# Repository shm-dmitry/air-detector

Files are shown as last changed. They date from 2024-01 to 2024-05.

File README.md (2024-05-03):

Project info
=======

Project released.

This project contains 2 boards with different sensor sets.

Board#1:
- CO2
- TVOC
- NOx
- Temperature
- Humidity
- PMx (dust)
- H2S (hydrogen sulfide)
- CO (carbon monoxide)
- O2 (oxygen)

Board#2
- TVOC
- NOx
- Temperature
- Humidity
- H2S (hydrogen sulfide)
- Light (in percents, not in Lumens)

It controls:
- Exhaust fan 
- Cooling fan with speed control (fan_pwm driver) 

Additional features:
- Integrates with any smart-house system via MQTT protocol (over WIFI)
- Contains touchpad supports multi-click (single click, double click, tripple click etc)
- Contains RGB led to indicate some internal state you want
- OTA updates - just publish new firmware on your local HTTP server and send URL to it into MQTT topic

3D models
=======
- Board#1 - 3d/box-slepingroom*.stl
- Board#2 - 3d/box-bathroom*.stl

Home assistant files
=======
- Board#1 - hass/board1
- Board#2 - hass/board2

Project status
=======

- Board#1 - Done
- Board#2 - Done

Photos
=======
Board#1:






Board#2:
изображение
изображение
изображение
изображение

MQTT Broker data:

Board#1: topic `/air/1`

Board#2: topic `/air/0`

изображение

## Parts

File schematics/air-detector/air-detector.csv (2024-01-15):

Source: | /opt/work-iot/air-detector/schematics/air-detector/air-detector.kicad_sch
Date: | Вт 09 янв 2024 12:32:36
Tool: | Eeschema 7.0.10-7.0.10~ubuntu22.04.1
Generator: | /usr/share/kicad/plugins/bom_csv_grouped_by_value_with_fp.py
Component Count: | 132
Ref | Qnty | Value | Cmp name | Footprint | Description | Vendor | DNP
C1, C2, C3, C6, C27, C28, C29 | 7 | 10 uF | C | Capacitor_SMD:C_0603_1608Metric | Unpolarized capacitor
C4, C11, C30, C33 | 4 | 1000 uF | C_Polarized | Capacitor_THT:CP_Radial_D8.0mm_P3.50mm | Polarized capacitor
C5, C9, C17, C31, C32, C36 | 6 | 22 uF | C | Capacitor_SMD:C_1210_3225Metric | Unpolarized capacitor
C7, C8, C10, C12, C14, C15, C19, C20, C21, C23, C24, C25, C34, C39, C40, C41 | 16 | 1 uF | C | Capacitor_SMD:C_0603_1608Metric | Unpolarized capacitor
C13, C26 | 2 | 100 nF | C | Capacitor_SMD:C_0603_1608Metric | Unpolarized capacitor
C16, C22, C35 | 3 | 100 uF | C | Capacitor_SMD:C_0603_1608Metric | Unpolarized capacitor
C18, C37, C38 | 3 | 0.1 uF | C | Capacitor_SMD:C_0603_1608Metric | Unpolarized capacitor
D4 | 1 | SK6812 | SK6812 | LED_SMD:LED_SK6812_PLCC4_5.0x5.0mm_P3.2mm | RGB LED with integrated controller
D8, D9 | 2 | PRTR5V0U2X | SP0503BAHT | Package_TO_SOT_SMD:SOT-143 | TVS Diode Array, 5.5V Standoff, 3 Channels, SOT-143 package
H1, H2, H3, H4, H5, H6, H7, H8, H9 | 9 | MountingHole | MountingHole | MountingHole:MountingHole_2.2mm_M2 | Mounting Hole without connection
J1, J9 | 2 | USB_C_Receptacle_USB2.0 | USB_C_Receptacle_USB2.0 | Library:USB_C_P16_MIDMOUNT_1.6 | USB 2.0-only Type-C Receptacle connector
J2 | 1 | Touch sensor | Conn_01x02_Socket | Connector_JST:JST_XH_B2B-XH-A_1x02_P2.50mm_Vertical | Generic connector, single row, 01x02, script generated
J3, J10 | 2 | 5V input | Conn_01x02_Socket | Connector_JST:JST_XH_B2B-XH-A_1x02_P2.50mm_Vertical | Generic connector, single row, 01x02, script generated
J4, J8 | 2 | BME280 | Conn_01x04_Socket | Connector_JST:JST_XH_B4B-XH-A_1x04_P2.50mm_Vertical | Generic connector, single row, 01x04, script generated
J5 | 1 | PMS7003 | Conn_02x05_Odd_Even | Connector_JST:JST_XH_B10B-XH-A_1x10_P2.50mm_Vertical | Generic connector, double row, 02x05, odd/even pin numbering scheme (row 1 odd numbers, row 2 even numbers), script generated (kicad-library-utils/schlib/autogen/connector/)
J6 | 1 | Ext FAN | Conn_01x02_Socket | Connector_JST:JST_XH_B2B-XH-A_1x02_P2.50mm_Vertical | Generic connector, single row, 01x02, script generated
J7 | 1 | FAN | Conn_01x02_Socket | Connector_JST:JST_XH_B2B-XH-A_1x02_P2.50mm_Vertical | Generic connector, single row, 01x02, script generated
J11 | 1 | MHZ19B | Conn_01x04_Socket | Connector_JST:JST_XH_B4B-XH-A_1x04_P2.50mm_Vertical | Generic connector, single row, 01x04, script generated
JP1, JP3 | 2 | FLUSH | SolderJumper_2_Open | Jumper:SolderJumper-2_P1.3mm_Open_TrianglePad1.0x1.5mm | Solder Jumper, 2-pole, open
JP2, JP4 | 2 | RESET | SolderJumper_2_Open | Jumper:SolderJumper-2_P1.3mm_Open_TrianglePad1.0x1.5mm | Solder Jumper, 2-pole, open
Q1, Q2, Q6, Q7 | 4 | BC847 | BC847 | Package_TO_SOT_SMD:SOT-23 | 0.1A Ic, 45V Vce, NPN Transistor, SOT-23
Q3, Q4, Q5 | 3 | IRLML0030 | IRLML0030 | Package_TO_SOT_SMD:SOT-23 | 5.3A Id, 30V Vds, 27mOhm Rds, N-Channel HEXFET Power MOSFET, SOT-23
R1, R24 | 2 | 22K | R | Resistor_SMD:R_0805_2012Metric | Resistor
R2, R25 | 2 | 44K | R | Resistor_SMD:R_0805_2012Metric | Resistor
R3, R14, R15, R26, R29, R31 | 6 | 1K | R | Resistor_SMD:R_0805_2012Metric | Resistor
R4, R5, R7, R9, R17, R18, R22, R23, R27, R28, R30, R32, R33, R34, R35, R36, R37 | 17 | 10K | R | Resistor_SMD:R_0805_2012Metric | Resistor
R6 | 1 | 100 | R | Resistor_SMD:R_0805_2012Metric | Resistor
R8 | 1 | 10K | R_Photo | Resistor_THT:R_Axial_DIN0207_L6.3mm_D2.5mm_P2.54mm_Vertical | Photoresistor
R10, R11, R12, R13 | 4 | 3K3 | R | Resistor_SMD:R_0805_2012Metric | Resistor
R16, R20 | 2 | 4R7 | R | Resistor_SMD:R_0805_2012Metric | Resistor
R19 | 1 | 500 | R | Resistor_SMD:R_0805_2012Metric | Resistor
R21 | 1 | 30K | R | Resistor_SMD:R_0805_2012Metric | Resistor
RV1 | 1 | 5K | R_Potentiometer | Potentiometer_THT:Potentiometer_Runtron_RM-065_Vertical | Potentiometer
RV2, RV3 | 2 | 200K | R_Potentiometer | Potentiometer_THT:Potentiometer_Runtron_RM-065_Vertical | Potentiometer
SW1, SW2, SW3, SW4 | 4 | KLS7-TS3601-5.0-180 | SW_Push | Library:SW_PUSH_P6.5_W3.5 | Push button switch, generic, two pins
U1, U13 | 2 | CP2102N-Axx-xQFN28 | CP2102N-Axx-xQFN28 | Package_DFN_QFN:QFN-28-1EP_5x5mm_P0.5mm_EP3.35x3.35mm | USB to UART master bridge, QFN-28
U2 | 1 | O2A2 | O2A2 | Library:O2A2
U3 | 1 | LM358ADR | LM2904 | Package_SO:SOP-8_5.28x5.23mm_P1.27mm | Dual Operational Amplifiers, DIP-8/SOIC-8/TSSOP-8/VSSOP-8
U4, U14 | 2 | AMS1117-3.3 | AMS1117-3.3 | Package_TO_SOT_SMD:SOT-223-3_TabPin2 | 1A Low Dropout regulator, positive, 3.3V fixed output, SOT-223
U5 | 1 | MQ-7 | MQ-6 | Sensor:MQ-6 | Semiconductor Sensor for Flammable Gas
U6, U12 | 2 | MQ-136 | MQ-6 | Sensor:MQ-6 | Semiconductor Sensor for Flammable Gas
U8, U15 | 2 | ESP32-WROOM-32 | ESP32-WROOM-32 | RF_Module:ESP32-WROOM-32 | RF Module, ESP32-D0WDQ6 SoC, Wi-Fi 802.11b/g/n, Bluetooth, BLE, 32-bit, 2.7-3.6V, onboard antenna, SMD
U10, U11 | 2 | SGP41 | SGP41 | footprints:XDCR_SGP41-D-R4

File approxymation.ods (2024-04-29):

X | 10 | Y | 1,45 | 1,45000054672845
X | 25 | Y | 1,13 | 1,13000041804603
X | 40 | Y | 1 | 1,00000045075979
X | 55 | Y | 0,92 | 0,920000474232243
X | 70 | Y | 0,87 | 0,870000487142095
OFFSET | 20
A | 0,746382 | 1,689218
B | 0,031302 | 0,266425
C | 0,786563
Test: | X | 44,2 | Y | 0,973684573079186

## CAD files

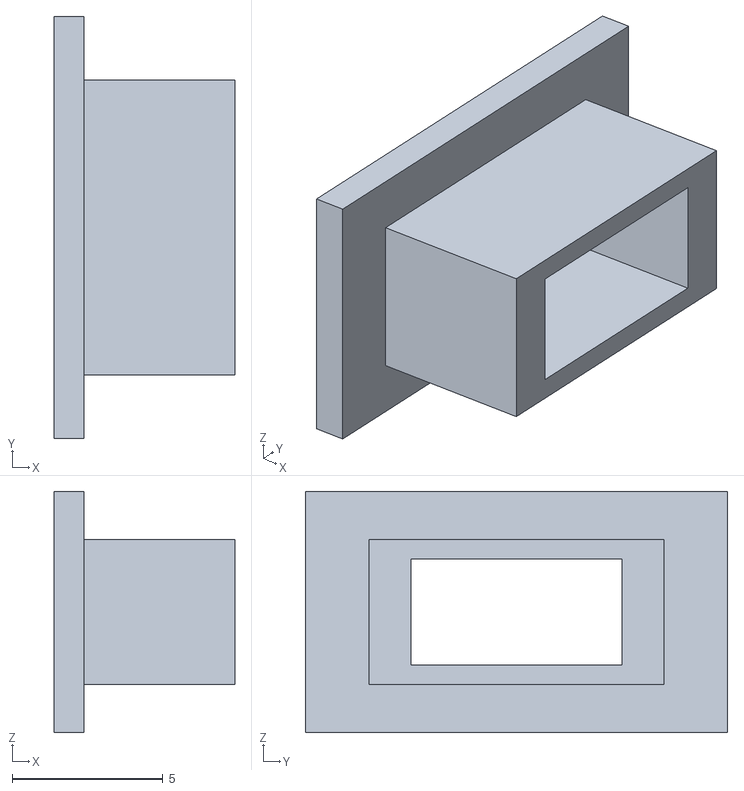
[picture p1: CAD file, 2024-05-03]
3d/box-slepingroom-wire-holder.stl
6.00 x 14.0 x 8.00

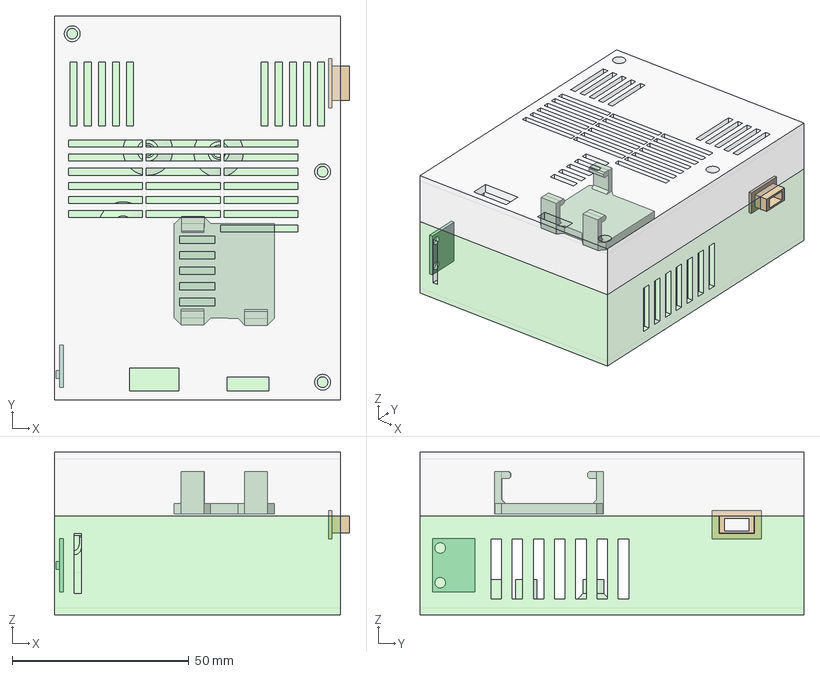
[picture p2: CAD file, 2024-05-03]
3d/box-slepingroom.FCStd
83.4 x 108.5 x 46.0 mm
bme280
cup
mhz19b-lock
wire-holder

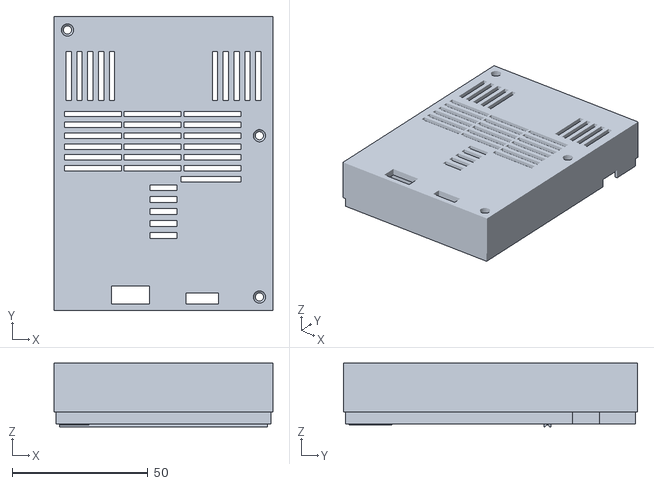
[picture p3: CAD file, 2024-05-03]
3d/box-slepingroom-cup.stl
80.8 x 108.5 x 23.5

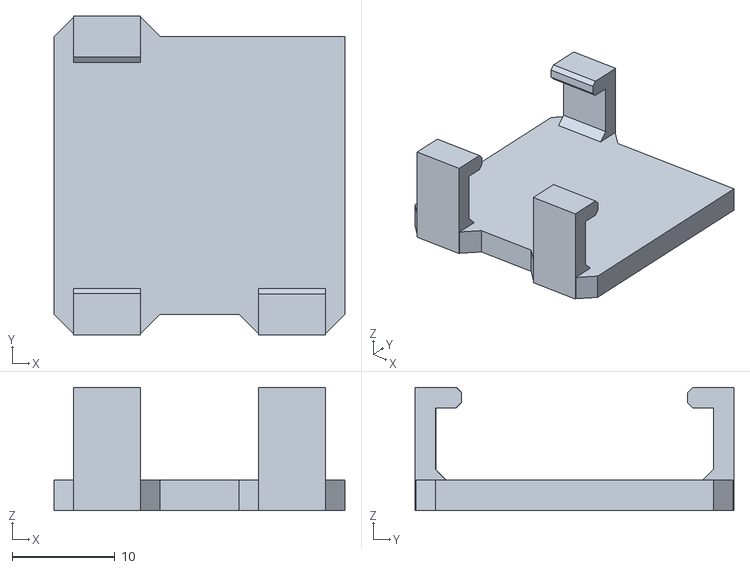
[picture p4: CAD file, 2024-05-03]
3d/box-slepingroom-mhz19b-lock.stl
28.3 x 31.0 x 12.0

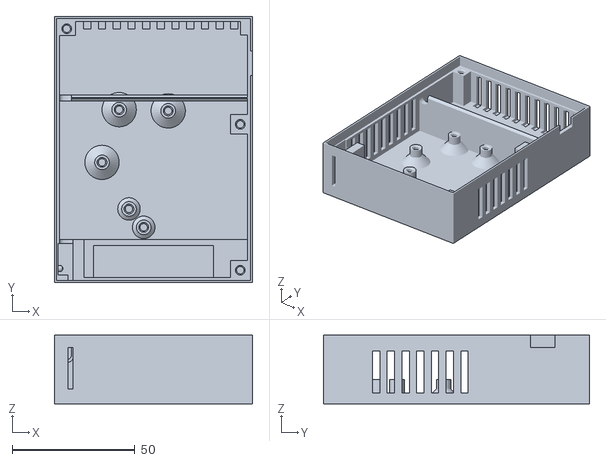
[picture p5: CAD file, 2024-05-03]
3d/box-slepingroom-box.stl
80.8 x 108.5 x 28.0

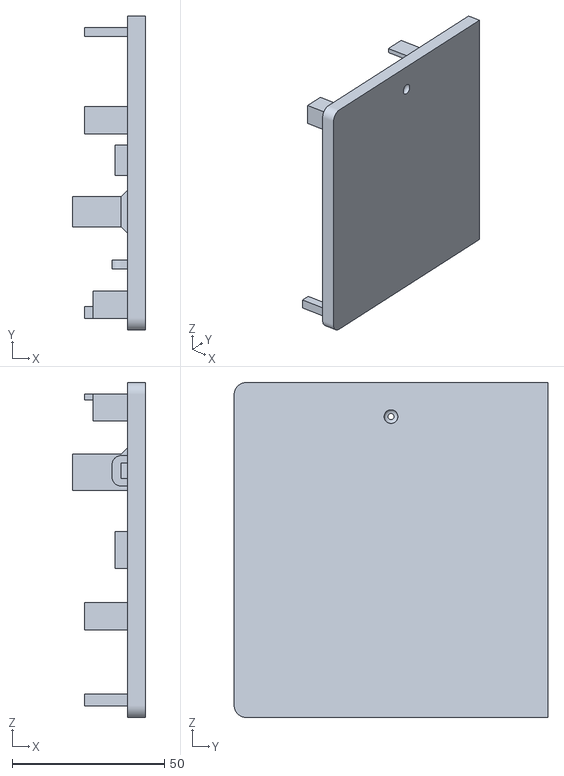
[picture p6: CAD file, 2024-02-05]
3d/box-bathroom-cup.stl
24.0 x 103.0 x 110.0

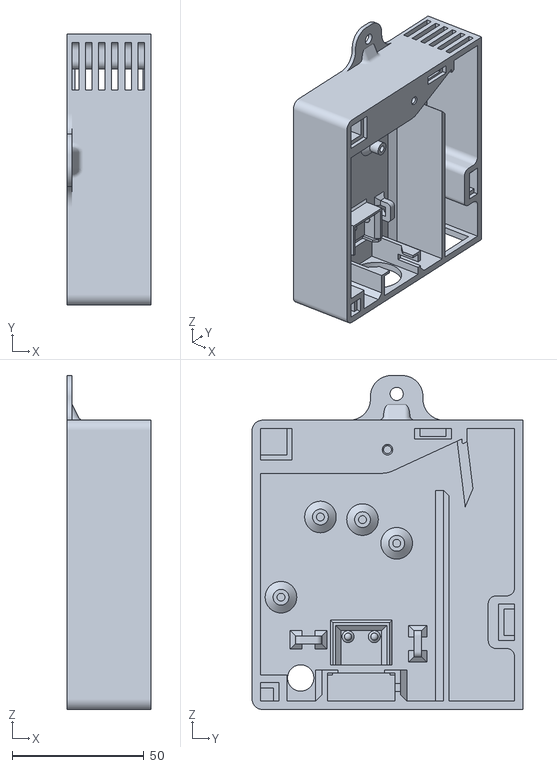
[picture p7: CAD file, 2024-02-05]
3d/box-bathroom-box.stl
32.0 x 103.0 x 127.0

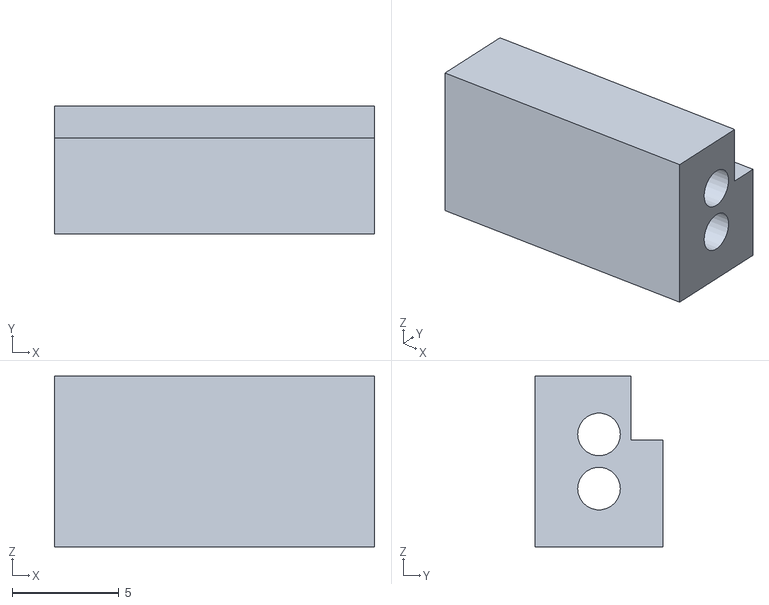
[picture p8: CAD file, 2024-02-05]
3d/box-bathroom-light-sensor-holder.stl
15.0 x 6.00 x 8.00

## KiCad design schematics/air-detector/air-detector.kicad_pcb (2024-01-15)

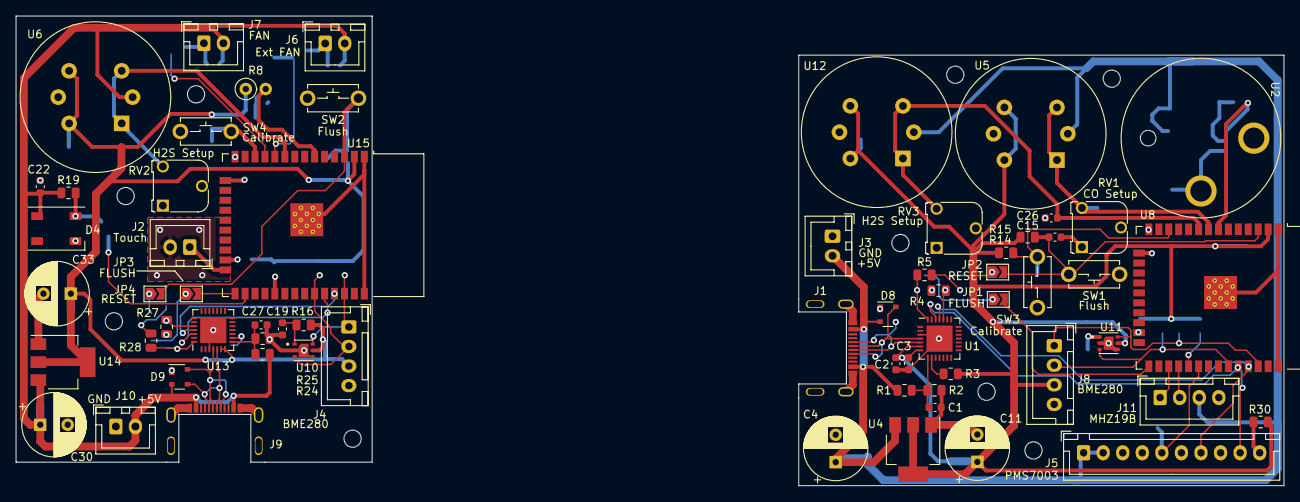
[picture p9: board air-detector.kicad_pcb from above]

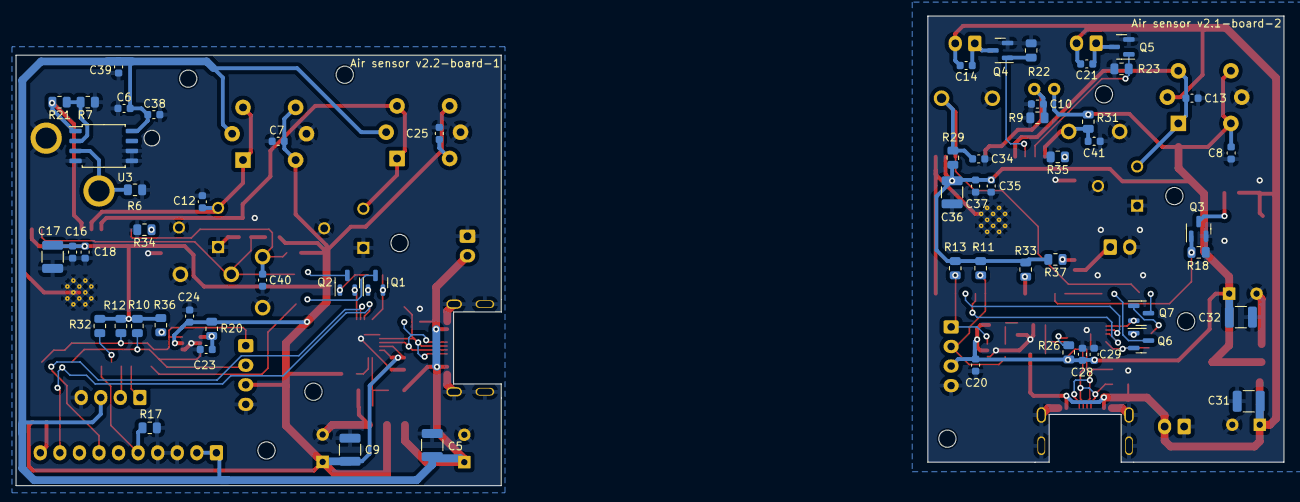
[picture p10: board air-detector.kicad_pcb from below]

Board: 2 copper layers, 162.0 x 60.0 mm, 132 parts (59 on the bottom side), 66 nets.

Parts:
C1, C2, C3, C6, C27, C28, C29: 10 uF; C_0603_1608Metric
C4, C11, C30, C33: 1000 uF; CP_Radial_D8.0mm_P3.50mm
C5, C9, C17, C31, C32, C36: 22 uF; C_1210_3225Metric
C7, C8, C10, C12, C14, C15, C19, C20, C21, C23, C24, C25, C34, C39, C40, C41: 1 uF; C_0603_1608Metric
C13, C26: 100 nF; C_0603_1608Metric
C16, C22, C35: 100 uF; C_0603_1608Metric
C18, C37, C38: 0.1 uF; C_0603_1608Metric
D4: SK6812; LED_SK6812_PLCC4_5.0x5.0mm_P3.2mm
D8, D9: PRTR5V0U2X; SOT-143
H1, H2, H3, H4, H5, H6, H7, H8, H9: MountingHole; MountingHole_2.2mm_M2
J1, J9: USB_C_Receptacle_USB2.0; USB_C_P16_MIDMOUNT_1.6
J2: Touch sensor; JST_XH_B2B-XH-A_1x02_P2.50mm_Vertical
J3, J10: 5V input; JST_XH_B2B-XH-A_1x02_P2.50mm_Vertical
J4, J8: BME280; JST_XH_B4B-XH-A_1x04_P2.50mm_Vertical
J5: PMS7003; JST_XH_B10B-XH-A_1x10_P2.50mm_Vertical
J6: Ext FAN; JST_XH_B2B-XH-A_1x02_P2.50mm_Vertical
J7: FAN; JST_XH_B2B-XH-A_1x02_P2.50mm_Vertical
J11: MHZ19B; JST_XH_B4B-XH-A_1x04_P2.50mm_Vertical
JP1, JP3: FLUSH; SolderJumper-2_P1.3mm_Open_TrianglePad1.0x1.5mm
JP2, JP4: RESET; SolderJumper-2_P1.3mm_Open_TrianglePad1.0x1.5mm
Q1, Q2, Q6, Q7: BC847; SOT-23
Q3, Q4, Q5: IRLML0030; SOT-23
R1, R24: 22K; R_0805_2012Metric
R2, R25: 44K; R_0805_2012Metric
R3, R14, R15, R26, R29, R31: 1K; R_0805_2012Metric
R4, R5, R7, R17, R18, R22, R23, R27, R28, R30, R32, R33, R34, R35, R36, R37: 10K; R_0805_2012Metric
R6: 100; R_0805_2012Metric
R8: 100K; R_Axial_DIN0207_L6.3mm_D2.5mm_P2.54mm_Vertical
R9: 100K; R_0805_2012Metric
R10, R11, R12, R13: 3K3; R_0805_2012Metric
R16, R20: 4R7; R_0805_2012Metric
R19: 500; R_0805_2012Metric
R21: 30K; R_0805_2012Metric
RV1: 10K; Potentiometer_Runtron_RM-065_Vertical
RV2, RV3: 20K; Potentiometer_Runtron_RM-065_Vertical
SW1, SW2, SW3, SW4: KLS7-TS3601-5.0-180; SW_PUSH_P6.5_W3.5
U1, U13: CP2102N-Axx-xQFN28; QFN-28-1EP_5x5mm_P0.5mm_EP3.35x3.35mm
U2: O2A2
U3: LM358ADR; SOP-8_5.28x5.23mm_P1.27mm
U4, U14: AMS1117-3.3; SOT-223-3_TabPin2
U5: MQ-7; MQ-6
U6, U12: MQ-136; MQ-6
U8, U15: ESP32-WROOM-32
U10, U11: SGP41; XDCR_SGP41-D-R4

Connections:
/board1/+3V3: C2.1, C3.1, C7.2, C9.2, C11.1, C16.2, C17.2, C18.1, C24.2, C25.2, J8.3, R3.2, R10.1, R12.1, R14.1, R15.1, R20.1, R30.2, R32.2, R36.2, U1.6 (VDD), U1.7 (VREGIN), U4.2 (VO), U5.4 (A2), U5.6 (A1), U8.2 (VDD), U11.5 (VCC_H), U12.4 (A2), U12.6 (A1)
/board1/+5V: C4.1, C5.2, C6.2, C38.2, C39.2, D8.2 (K), J1.A4 (VBUS), J1.A9 (VBUS), J1.B4 (VBUS), J1.B9 (VBUS), J3.2, J5.1, J5.2, J11.3, R1.1, U3.8 (V+), U4.3 (VI), U5.2 (VH+), U12.2 (VH+)
/board1/CO: C12.2, RV1.3, U5.1 (B1), U5.3 (B2), U8.8 (IO32)
/board1/H2S: C26.2, RV3.3, U8.9 (IO33), U12.1 (B1), U12.3 (B2)
/board1/O2: R21.2, U3.1, U8.7 (IO35)
/board1/PMS7003_ENABLE: J5.5, R17.2, U8.30 (IO18)
/board1/RXD_2_3V3: J11.2, U8.28 (IO17)
/board1/RXD_3V3: J5.7, U1.25 (RXD), U8.35 (TXD0/IO1)
/board1/SCL_3V3: J8.1, R12.2, U8.36 (IO22), U11.6 (SCL)
/board1/SDA_3V3: J8.2, R10.2, U8.33 (IO21), U11.3 (SDA)
/board1/TXD_2_3V3: J11.1, U8.27 (IO16)
/board1/TXD_3V3: J5.9, U1.26 (TXD), U8.34 (RXD0/IO3)
/board2/+3V3: C8.2, C20.2, C28.1, C29.1, C32.2, C33.1, C35.2, C36.2, C37.1, J4.3, R8.1, R11.1, R13.1, R16.1, R26.2, R29.1, R31.1, R33.2, R37.2, U6.4 (A2), U6.6 (A1), U10.5 (VCC_H), U13.6 (VDD), U13.7 (VREGIN), U14.2 (VO), U15.2 (VDD)
/board2/+5V: C14.2, C21.2, C22.2, C30.1, C31.2, D4.3 (VDD), D9.2 (K), J6.2, J7.2, J9.A4 (VBUS), J9.A9 (VBUS), J9.B4 (VBUS), J9.B9 (VBUS), J10.2, R19.1, R24.1, U6.2 (VH+), U14.3 (VI)
/board2/EXT_FAN_ENABLE: Q4.1 (G), R22.1, U15.10 (IO25)
/board2/FAN_ENABLE: Q5.1 (G), R23.1, U15.11 (IO26)
/board2/H2S: C13.2, RV2.3, U6.1 (B1), U6.3 (B2), U15.9 (IO33)
/board2/LIGHT: C10.2, R8.2, R9.1, U15.6 (IO34)
/board2/RGB_CONTROL#: Q3.1 (G), R18.1, U15.26 (IO4)
/board2/SCL_3V3: J4.1, R13.2, U10.6 (SCL), U15.36 (IO22)
/board2/SDA_3V3: J4.2, R11.2, U10.3 (SDA), U15.33 (IO21)
/board2/TOUCH_SENSOR: J2.1, U15.24 (IO2)
/core1/CALIBRATE_BUTTON: C41.1, R31.2, SW4.2, U15.12 (IO27)
/core1/D+: D9.4 (K), J9.A6 (D+), J9.B6 (D+), U13.4 (D+)
/core1/D-: D9.3 (K), J9.A7 (D-), J9.B7 (D-), U13.5 (D-)
/core1/ESP32_ENABLE: C34.1, JP4.2 (B), R29.2, SW2.2, U15.3 (EN)
/core1/ESP32_FLUSH: JP3.2 (B), U15.25 (IO0)
/core1/GND: C8.1, C10.1, C13.1, C19.1, C20.1, C22.1, C27.2, C28.2, C29.2, C30.2, C31.1, C32.1, C33.2, C34.2, C35.1, C36.1, C37.2, C41.2, D4.1 (VSS), D9.1 (A), J2.2, J4.4, J9.A1 (GND), J9.A12 (GND), J9.B1 (GND), J9.B12 (GND), J9.S1 (SHIELD), J10.1, Q3.2 (S), Q4.2 (S), Q5.2 (S), R9.2, R18.2, R22.2, R23.2, R25.2, R35.2, RV2.1, RV2.2, SW2.1, SW4.1, U6.5 (VH-), U10.2 (GND1), U10.4 (GND2), U10.7 (PAD), U13.3 (GND), U13.29 (GND), U14.1 (GND), U15.1 (GND), U15.15 (GND), U15.38 (GND), U15.39 (GND)
/core1/RXD_3V3: U13.25 (RXD), U15.35 (TXD0/IO1)
/core1/TXD_3V3: U13.26 (TXD), U15.34 (RXD0/IO3)
/core/CALIBRATE_BUTTON: C40.1, R14.2, SW3.2, U8.12 (IO27)
/core/D+: D8.4 (K), J1.A6 (D+), J1.B6 (D+), U1.4 (D+)
/core/D-: D8.3 (K), J1.A7 (D-), J1.B7 (D-), U1.5 (D-)
/core/ESP32_ENABLE: C15.1, JP2.2 (B), R15.2, SW1.2, U8.3 (EN)
/core/ESP32_FLUSH: JP1.2 (B), U8.25 (IO0)
/core/GND: C1.2, C2.2, C3.2, C4.2, C5.1, C6.1, C7.1, C9.1, C11.2, C12.1, C15.2, C16.1, C17.1, C18.2, C23.1, C24.1, C25.1, C26.1, C38.1, C39.1, C40.2, D8.1 (A), J1.A1 (GND), J1.A12 (GND), J1.B1 (GND), J1.B12 (GND), J1.S1 (SHIELD), J3.1, J5.3, J5.4, J8.4, J11.4, R2.2, R6.2, R7.2, R17.1, R34.2, RV1.1, RV1.2, RV3.1, RV3.2, SW1.1, SW3.1, U1.3 (GND), U1.29 (GND), U2.3 (GND), U3.4 (V-), U3.5 (+), U3.6 (-), U4.1 (GND), U5.5 (VH-), U8.1 (GND), U8.15 (GND), U8.38 (GND), U8.39 (GND), U11.2 (GND1), U11.4 (GND2), U11.7 (PAD), U12.5 (VH-)
unnamed: D4.2 (DIN), Q3.3 (D), R19.2
unnamed: J5.10, R30.1
unnamed: C14.1, J6.1, Q4.3 (D)
unnamed: C21.1, J7.1, Q5.3 (D)
unnamed: JP1.1 (A), Q1.3 (C)
unnamed: JP2.1 (A), Q2.3 (C)
unnamed: JP3.1 (A), Q6.3 (C)
unnamed: JP4.1 (A), Q7.3 (C)
unnamed: Q1.1 (B), R4.2
unnamed: Q1.2 (E), R5.1, U1.28 (~DTR)
unnamed: Q2.1 (B), R5.2
unnamed: Q2.2 (E), R4.1, U1.24 (~RTS)
unnamed: Q6.1 (B), R27.2
unnamed: Q6.2 (E), R28.1, U13.28 (~DTR)
unnamed: Q7.1 (B), R28.2
unnamed: Q7.2 (E), R27.1, U13.24 (~RTS)
unnamed: C1.1, R1.2, R2.1, U1.8 (VBUS)
unnamed: R3.1, U1.9 (~RST)
unnamed: R6.1, U2.2 (OUT), U3.3 (+)
unnamed: R7.1, R21.1, U3.2 (-)
unnamed: R32.1, U8.29 (IO5)
unnamed: R34.1, U8.14 (IO12)
unnamed: R36.1, U8.23 (IO15)
unnamed: C19.2, R16.2, U10.1 (VCC)
unnamed: C23.2, R20.2, U11.1 (VCC)
unnamed: C27.1, R24.2, R25.1, U13.8 (VBUS)
unnamed: R26.1, U13.9 (~RST)
unnamed: R33.1, U15.29 (IO5)
unnamed: R35.1, U15.14 (IO12)
unnamed: R37.1, U15.23 (IO15)

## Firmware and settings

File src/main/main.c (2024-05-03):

#include <stdio.h>
#include <stdbool.h>
#include <unistd.h>

#include "sdkconfig.h"

#include "log/log.h"
#include "led/led.h"
#include "i2c/sgp41/sgp41.c"
#include "i2c/i2c_impl.h"
#include "touchpad/touchpad.h"
#include "freertos/FreeRTOS.h"
#include "freertos/task.h"
#include "fans/fan/fan.h"
#include "fans/fan_pwm/fan_pwm.h"
#include "adc/mq136/mq136.h"
#include "adc/light/light.h"
#include "adc/o2a2/o2a2.h"
#include "adc/mq7/mq7.h"
#include "adc/adc.h"
#include "common/wifi.h"
#include "common/nvs_rw.h"
#include "common/mqtt.h"
#include "uart/mh_z19b/mh_z19b.h"
#include "uart/pms7003/pms7003.h"

void app_main(void)
{
	nvs_init();
	wifi_init();

#if CONFIG_LED_ENABLED
	led_init();
#endif

#if CONFIG_I2C_ENABLED
	i2c_init_driver(CONFIG_I2C_GPIO_SDA, CONFIG_I2C_GPIO_SCL);
#endif

#if CONFIG_BME280_ENABLED
	bme280_init();
#endif

#if CONFIG_SGP41_ENABLED
	sgp41_init();
#endif

#if CONFIG_MQ136_ENABLED || CONFIG_LIGHT_ENABLED
	adc_init();
#endif

#if CONFIG_MQ136_ENABLED
	mq136_init();
#endif

#if CONFIG_MQ7_ENABLED
	mq7_init();
#endif

#if CONFIG_LIGHT_ENABLED
	light_init();
#endif

#if CONFIG_O2A2_ENABLED
	o2a2_init();
#endif

#if CONFIG_TOUCHPAD_ENABLED
	touchpad_init();
#endif

#if CONFIG_FAN_ENABLED
	fan_init();
#endif

#if CONFIG_FANPWM_ENABLED
	fanpwm_init();
#endif

#if CONFIG_MHZ19B_ENABLED
	mhz19b_init();
#endif

#if CONFIG_PMS7003_ENABLED
	pms7003_init();
#endif

	mqtt_start();

	LOGI(LOG_MAIN, "Application started");

	while(true) {
		vTaskDelay(1000 / portTICK_PERIOD_MS);
	}
}

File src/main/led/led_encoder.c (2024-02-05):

#include "led_encoder.h"

#include "freertos/FreeRTOS.h"
#include "freertos/task.h"
#include "freertos/queue.h"
#include "driver/rmt_encoder.h"

#include "../log/log.h"

typedef struct {
    rmt_encoder_t base;
    rmt_encoder_t *copy_encoder;
    rmt_encoder_t *bytes_encoder;
    rmt_symbol_word_t reset_chanel_symbol;
    uint8_t bytes_sent;
} rmt_fm_encoder_t;

static size_t IRAM_ATTR led_isr_rmt_encode(rmt_encoder_t *encoder, rmt_channel_handle_t channel, const void *primary_data, size_t data_size, rmt_encode_state_t *ret_state) {
	rmt_fm_encoder_t *encoder_data = __containerof(encoder, rmt_fm_encoder_t, base);
    rmt_encode_state_t session_state = RMT_ENCODING_RESET;
    rmt_encode_state_t state = RMT_ENCODING_RESET;
    size_t encoded_symbols = 0;
    rmt_encoder_handle_t bytes_encoder = encoder_data->bytes_encoder;
    rmt_encoder_handle_t copy_encoder = encoder_data->copy_encoder;

    if (encoder_data->bytes_sent == 0) {
		encoded_symbols += copy_encoder->encode(copy_encoder, channel, &encoder_data->reset_chanel_symbol,
												sizeof(rmt_symbol_word_t), &session_state);
		if (session_state & RMT_ENCODING_COMPLETE) {
			encoder_data->bytes_sent = 1;
		}
		if (session_state & RMT_ENCODING_MEM_FULL) {
			state |= RMT_ENCODING_MEM_FULL;
			goto out;
		}
    }

    if (encoder_data->bytes_sent < data_size + 1) {
		encoded_symbols += bytes_encoder->encode(bytes_encoder,
												 channel,
												 primary_data,
												 data_size,
												 &session_state);
		if (session_state & RMT_ENCODING_COMPLETE) {
			encoder_data->bytes_sent += data_size;
		}
		if (session_state & RMT_ENCODING_MEM_FULL) {
			state |= RMT_ENCODING_MEM_FULL;
			goto out;
		}
    }

    encoded_symbols += copy_encoder->encode(copy_encoder, channel, &encoder_data->reset_chanel_symbol,
                                            sizeof(rmt_symbol_word_t), &session_state);
    if (session_state & RMT_ENCODING_COMPLETE) {
        encoder_data->bytes_sent = 0;
        state |= RMT_ENCODING_COMPLETE;
    }
    if (session_state & RMT_ENCODING_MEM_FULL) {
        state |= RMT_ENCODING_MEM_FULL;
        goto out;
    }

out:
    *ret_state = state;
    return encoded_symbols;
}

static esp_err_t IRAM_ATTR led_isr_rmt_del_encoder(rmt_encoder_t *encoder)
{
	rmt_fm_encoder_t *encoder_data = __containerof(encoder, rmt_fm_encoder_t, base);
    rmt_del_encoder(encoder_data->bytes_encoder);
    rmt_del_encoder(encoder_data->copy_encoder);
    free(encoder_data);
    return ESP_OK;
}

static esp_err_t IRAM_ATTR led_isr_rmt_reset_encoder(rmt_encoder_t *encoder)
{
	rmt_fm_encoder_t *encoder_data = __containerof(encoder, rmt_fm_encoder_t, base);
    rmt_encoder_reset(encoder_data->bytes_encoder);
    rmt_encoder_reset(encoder_data->copy_encoder);
    encoder_data->bytes_sent = 0;
    return ESP_OK;
}

void rmt_new_ir_nec_encoder(rmt_encoder_handle_t *ret_encoder) {
    rmt_fm_encoder_t *fm_encoder_iface = NULL;
    fm_encoder_iface = calloc(1, sizeof(rmt_fm_encoder_t));
    fm_encoder_iface->base.encode = led_isr_rmt_encode;
    fm_encoder_iface->base.del = led_isr_rmt_del_encoder;
    fm_encoder_iface->base.reset = led_isr_rmt_reset_encoder;

    // "reset" == LOW>80uS -> I use 90uS of LOW level to ensure command correctly read
    fm_encoder_iface->reset_chanel_symbol = (rmt_symbol_word_t) {
		.level0 = 0,
		.duration0 = 450,
		.level1 = 0,
		.duration1 = 450
    };

    // I have tolerance ±0.15uS, but I have min signal time 1.25±0.6uS.
    // So I increase time of each symbol part in tolerance limit to ensure
    // I use valid min signal time
    rmt_bytes_encoder_config_t bytes_encoder_config = {
    	// bit0: [LOW: 0.3uS; HIGH 0.9uS].
        .bit0 = {
            .level0 = 1,
            .duration0 = 4,
            .level1 = 0,
            .duration1 = 9,
        },
    	// bit1: [LOW: 0.6uS; HIGH 0.6uS].
        .bit1 = {
            .level0 = 1,
            .duration0 = 7,
            .level1 = 0,
            .duration1 = 6,
        },
		.flags = {
			.msb_first = true
		}
    };
    rmt_new_bytes_encoder(&bytes_encoder_config, &fm_encoder_iface->bytes_encoder);

    rmt_copy_encoder_config_t copy_encoder_config = {};
    rmt_new_copy_encoder(&copy_encoder_config, &fm_encoder_iface->copy_encoder);

    *ret_encoder = &fm_encoder_iface->base;
}

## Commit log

2024-01-15 MQTT integration for LED
2024-01-15 fan pwm integration
2024-01-16 light sensor integration
2024-01-16 fixed problem with ADC during start
    [light.c, main.c, mq136.c]
2024-01-17 I2C impl migrated to new API version
2024-01-17 fixed error while parsing RGBW value for led from MQTT
    [led.c]
2024-02-05 Device#1 assembled and ready to install in my appartment
    [box-bathroom-box.stl, box-bathroom-cup.stl, box-bathroom-light-sensor-holder.stl]
2024-02-05 fixed LED communication timning and default LED data level to reduce 10mA current consumption
    [led.c, led_encoder.c]
2024-02-05 MQ136 - added time/hum adjustment during calibration. Added auto-calibration when several times received negative ppm
2024-02-05 Added home assistant files for board-2
2024-02-06 fix mathematics issue in mq136 - I use 3.3V line offset for measurement, previous formulas was for 5V line offset
    [mq136.c]
2024-04-24 1. changes in o2a2 sensor; 2. prepare code for o2a2 sensor
    [air-detector.kicad_sch, board1.kicad_sch, board2.kicad_sch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]
2024-04-24 try to rewrite ADC work to custom framefork to avoid code duplication
    [adc_v_core.c, adc_v_core_nvs.c, fan.c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]
2024-04-25 added new drivers
2024-04-25 reduce code size by extracting uart-core common code
2024-04-27 after small test on hardware - added startup delay to O2 sensor; fixed issue in MQTT integration.
    [adc_v_core.c, mq136.c, mq7.c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]
2024-04-27 it was bad idea to use N-degree-polynom for approxymation without manual graph recheck. Approxymation formulas changed for MQ7 and MQ136
    [approxymation.ods]
2024-04-27 fix mistake in formulas
    [mq136.c, mq7.c]
2024-04-29 1. tested MHZ19B integration. 2. Tested BMW280 integration. 3. Fixed mistake in compensation formula in MQ7 integration
    [approxymation.ods]
2024-05-03 Box printed
    [box-slepingroom-box.stl, box-slepingroom-cup.stl, box-slepingroom-mhz19b-lock.stl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]
2024-05-03 1. added sdkconfig for board#1; added hass files for board1
2024-05-07 fixes in calibration algorithm
    [adc_v_core.c, adc_v_core_nvs.c]
2024-05-12 changes in calibration process for ADC-based sensors
2024-05-13 feature - read current settings without
